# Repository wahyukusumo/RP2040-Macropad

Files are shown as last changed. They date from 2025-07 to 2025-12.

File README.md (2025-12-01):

# RP2040 Macropad

This is a macropad firmware for Raspberry Pi Pico RP2040 written in Circuitpython. This firmware support up to 8 rotary encoders, 20 buttons, and a TFT display. Or you can just adjust it like however you like.

### Table of Contents
- [RP2040 Macropad](#rp2040-macropad)
    - [Table of Contents](#table-of-contents)
    - [Features](#features)
  - [🛠 Build](#-build)
    - [Hardwares Needed](#hardwares-needed)
    - [Schematic](#schematic)
    - [Software](#software)
    - [Installation](#installation)
    - [Configuration](#configuration)
    - [My Build Log](#my-build-log)

### Features

- 6 Rotary encoders.
- 240\*240 TFT Display to display information and image or gif. <sup><sub>*RP2040 will struggle to play gif btw</sub></sup>
-  [deej](https://github.com/omriharel/deej) rotary encoder support.

## 🛠 Build

You can adjust this build to fil what you need

### Hardwares Needed

- Raspberry Pi Pico
- 2 Expansion Board PCF8574
- 6 EC11 Rotary encoders
- 20 button switches
- ST7789 TFT Display
- Prefboard
- Wires

### Schematic

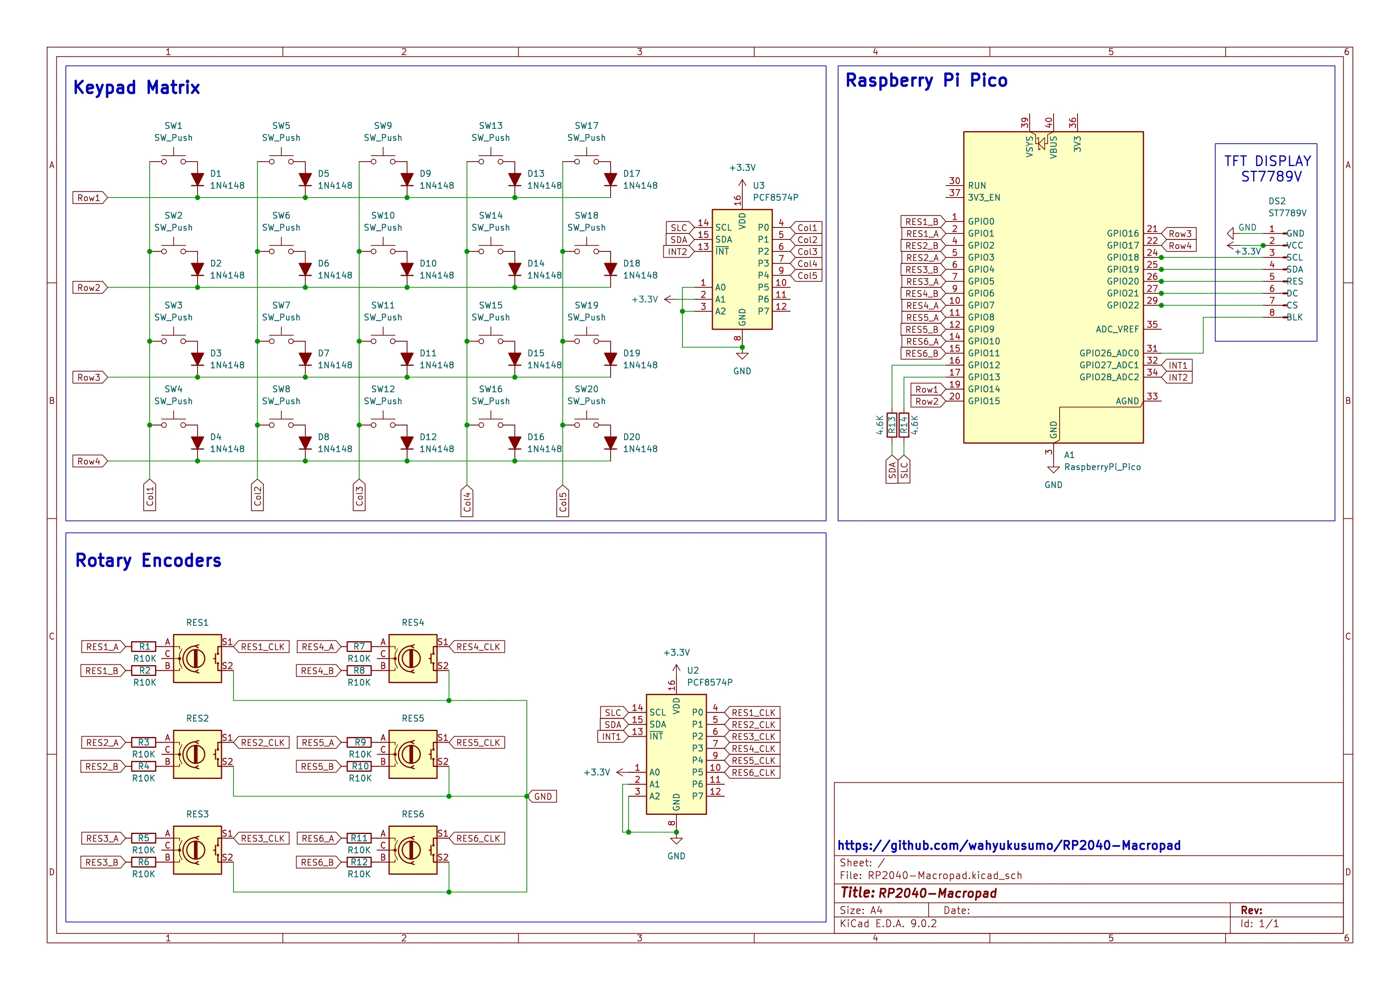
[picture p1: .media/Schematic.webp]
Schematic


### Software

- [Circuitpython v9](https://circuitpython.org/board/raspberry_pi_pico/)
- [Convert image to BMP](https://online-converting.com/image/convert2bmp/)
- [MPY Cross](https://adafruit-circuit-python.s3.amazonaws.com/index.html?prefix=bin/mpy-cross/windows/)

### Installation

- Install Circuitpython v9 to your Pi Pico
- Download or clone this repository
- Move all files inside _lib/lib-circuitpython-v9_ to your Pi Pico _lib_ folder
- Copy these file from this repository to your Pi Pico:
  - _config.py_
  - _code.py_
- If you want use custom font, you 
- This is what your Pi Pico directory should look like:
```
│   boot_out.txt
│   code.py
│   config.py
├───lib
│   │   adafruit_pcf8574.mpy
│   │   adafruit_pioasm.mpy
│   │   adafruit_st7789.mpy
│   │   deej.py
│   │   digitalio.mpy
│   │   rotaryio.mpy
│   │   rp2pio_dualincrementalencoder.mpy
│   │   macropad.mpy
│   │   display.mpy
│
├───media
├───fonts
```

### Configuration
- _config.py_ is to assign your microcontroller pins.
- _code.py_ is to assign your buttons and encoders actions.

### My Build Log
 _Update later..._

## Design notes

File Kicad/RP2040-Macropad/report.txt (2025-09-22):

Plotted to 'C:\Users\yvma\Documents\KiCad\RP2040-Macropad\RP2040-Macropad.pdf'.

Info: Done.
Info: Done.

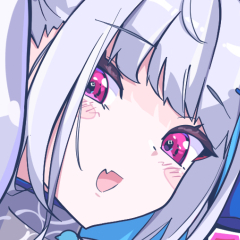
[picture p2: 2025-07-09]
image-to-bmp/myimages.jpg

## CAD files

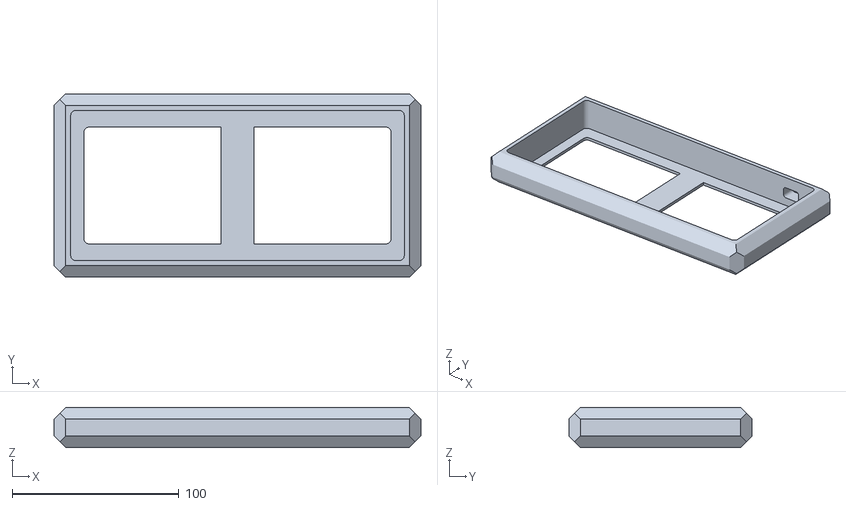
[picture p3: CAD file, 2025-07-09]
Case/macropad-trim.stl
220.0 x 110.0 x 24.0

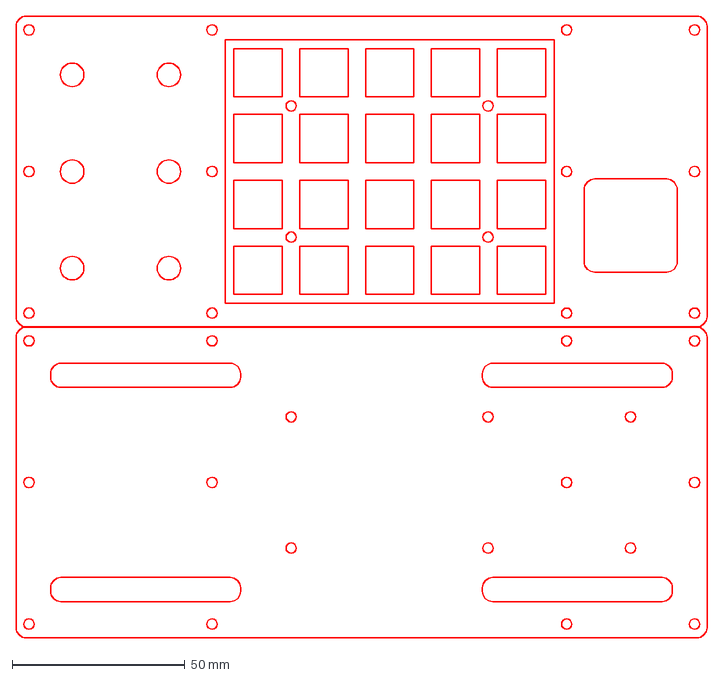
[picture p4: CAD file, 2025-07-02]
Case/macropad-ws2812.dxf
200.0 x 180.0 mm

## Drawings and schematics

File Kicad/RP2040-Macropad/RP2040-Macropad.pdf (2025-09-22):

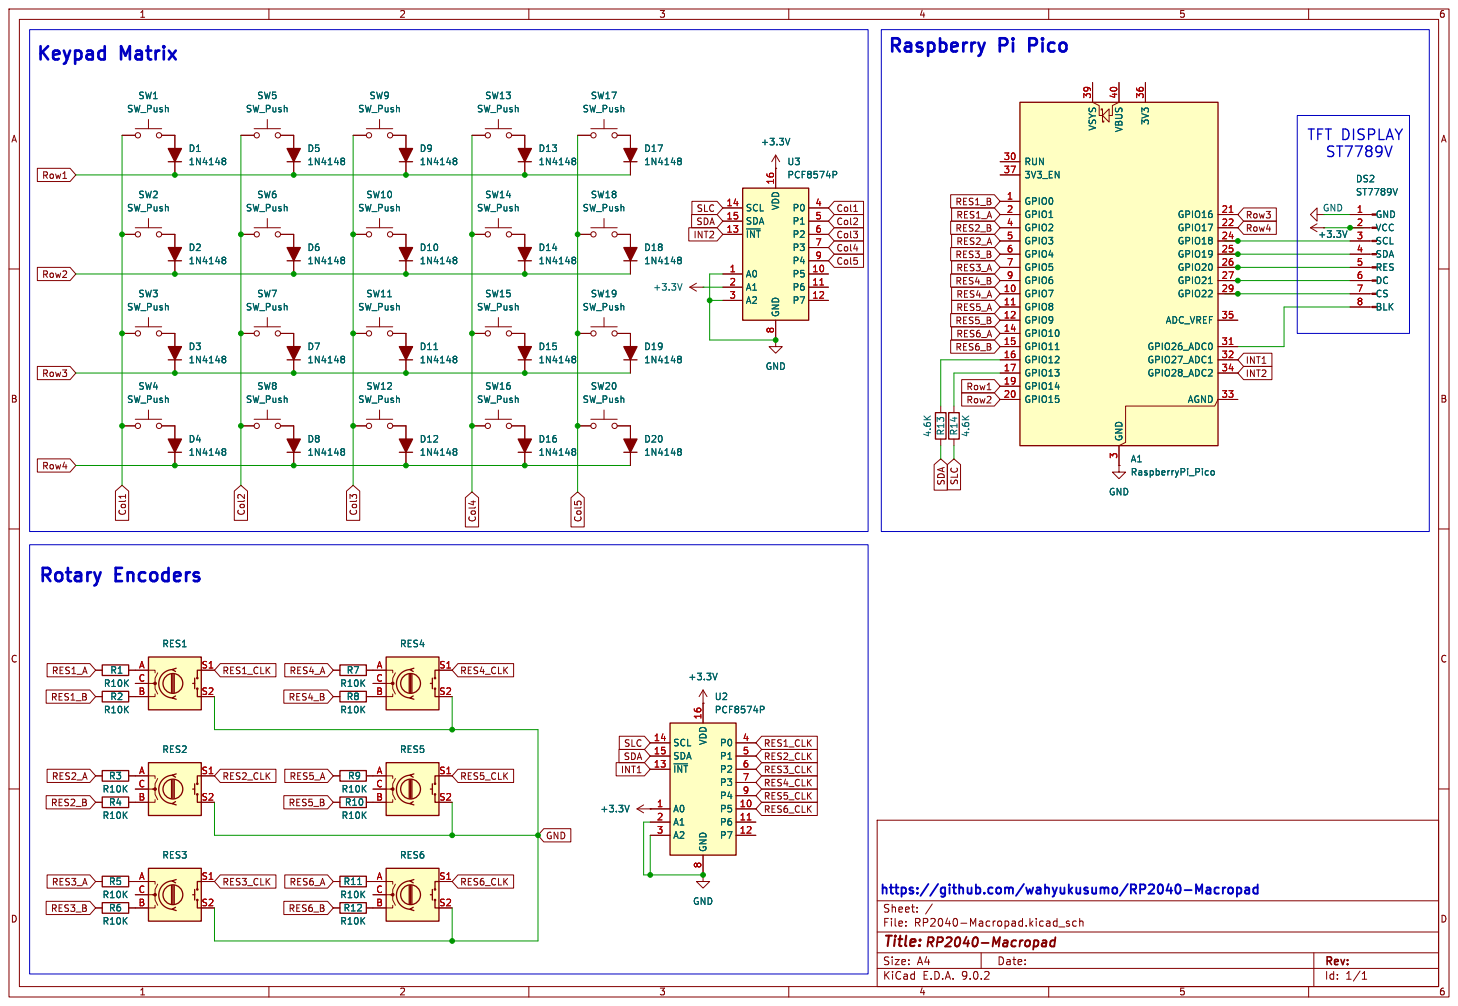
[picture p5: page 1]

INT2 RES6_A RES2_B RES1_A RES1_B RES6_B RES2_A RES3_B RES5_A RES4_A RES5_B RES4_B RES3_A https://github.com/wahyukusumo/RP2040-Macropad

Id: 1/1 Title: File: RP2040-Macropad.kicad_sch Sheet: / R3 R10K

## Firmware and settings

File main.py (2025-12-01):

import time
import board
import busio
import display
import config
from deej import Deej
from macropad import (
    HIDType as hid,
    ButtonInputType as BiT,
    Button,
    SplitRotaryEncoder,
    ButtonMatrix,
)
from adafruit_pcf8574 import PCF8574
from adafruit_hid.keycode import Keycode as key
from rp2pio_dualincrementalencoder import DualIncrementalEncoder
from adafruit_hid.consumer_control_code import ConsumerControlCode as cc_code


DEEJ = Deej(config.DEEJ_PROGRAMS)

SCREEN = display.DisplayScreen(
    pin_clock=config.DISPLAY_PINS["CLOCK"],
    pin_mosi=config.DISPLAY_PINS["MOSI"],
    pin_cs=config.DISPLAY_PINS["CS"],
    pin_dc=config.DISPLAY_PINS["DC"],
    pin_reset=config.DISPLAY_PINS["RESET"],
    pin_bl=config.DISPLAY_PINS["BL"],
    rotation=config.DISPLAY_PINS["ROTATION"],
)

ENCODERS, KEYPADS = config.input_map(SCREEN, DEEJ, BiT, key, hid, cc_code)


def init_expander(scl, sda):
    i2c = busio.I2C(scl, sda)
    # Wait for I2C to be ready
    while not i2c.try_lock():
        pass
    i2c.unlock()
    return i2c


def init_encoders(encoders_num):
    """This loop is for looping through encoders pin and .
    So if there's 6 rotary encoders, encoders_num = 6
    (0, 6 * 2, 4) mean we start from 0, and since each encoder have 2 pins, multiplied by 2.
    DualIncrementalEncoder require 4 pins so we split it by 4
    and it will append to dual_encoders as 3 object of DualIncrementalEncoder
    """
    dual_encoders = []
    for i in range(0, encoders_num * 2, 4):
        pins = [getattr(board, f"GP{j}") for j in range(i, i + 4)]
        init_dual_encoder = DualIncrementalEncoder(*pins)
        dual_encoders.append(init_dual_encoder)

    """ After we get DualIncrementalEncoders we need to get value of each encoder and
    apply action of the encoders
    """
    encoders = []
    for i in range(encoders_num):
        group = i // 2  # integer division groups every two items
        local_index = i % 2  # 0 or 1
        split_encoder = SplitRotaryEncoder(
            name=f"Encoder {i}",
            encoder=dual_encoders[group],
            index=local_index,
            actions=ENCODERS[config.ROTARY_ENCODERS_PHYSICAL_ORDER[i] - 1]["actions"],
        )
        encoders.append(split_encoder)

    return encoders


def init_button_encoders(i2c):
    expander = PCF8574(i2c, address=config.BUTTON_IO_EXPANDER_ADDRESS)
    buttons = []

    for encoder in ENCODERS:
        button_pin = expander.get_pin(encoder["button"]["pin"])
        button = Button(pin_button=button_pin, actions=encoder["button"]["actions"])
        buttons.append(button)
    return buttons


def init_volumes_label():
    labels = []
    for i in range(DEEJ.num_programs):
        y = 50 + (i - 1) * 25
        text = f"{DEEJ.volumes[i]} - {DEEJ.programs[i]}"
        label = SCREEN.label(text, x=15, y=y)
        labels.append(label)
    return labels


def main():
    i2c = init_expander(
        scl=config.IO_EXPANDER_PINS["SCL"], sda=config.IO_EXPANDER_PINS["SDA"]
    )

    encoders = init_encoders(config.ROTARY_ENCODERS_NUM)
    encoder_buttons = init_button_encoders(i2c)

    keypad = ButtonMatrix(
        actions=KEYPADS,
        expander=PCF8574(i2c, address=config.MATRIX_IO_EXPANDER_ADDRESS),
        rows=config.MATRIX_ROW_PINS,
        columns=config.MATRIX_COL_PINS,
    )

    if config.USE_DEEJ:
        labels = init_volumes_label()

    slideshow = display.Slideshow(SCREEN.images_group)
    # gif = display.PlayGif("media/mon.gif", SCREEN.gif_group, SCREEN.display)
    SCREEN.show_screen()

    while True:
        for encoder in encoders:
            turned = encoder.encoder_action()

            if turned and config.USE_DEEJ:
                labels[DEEJ.current].text = DEEJ.display

        for button in encoder_buttons:
            button.button_action()

        keypad.matrix_scanning()
        slideshow.update()
        # gif.update_gif()

        time.sleep(0.01)


if __name__ == "__main__":
    main()

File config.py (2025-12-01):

import board

IO_EXPANDER_PINS = {"SDA": board.GP12, "SCL": board.GP13}
MATRIX_IO_EXPANDER_ADDRESS = 0x25
BUTTON_IO_EXPANDER_ADDRESS = 0x20
DEEJ_PROGRAMS = ["Master", "Firefox", "Spotify", "Discord", "Apex"]

USE_DEEJ = False
DISPLAY_PINS = {
    "CLOCK": board.GP18,
    "MOSI": board.GP19,
    "CS": board.GP20,
    "DC": board.GP21,
    "RESET": board.GP22,
    "BL": board.GP23,
    "ROTATION": 180,
}

MATRIX_ROW_PINS = [board.GP14, board.GP15, board.GP17, board.GP24]
MATRIX_COL_PINS = [0, 1, 2, 3, 4]

ROTARY_ENCODERS_NUM = 6
ROTARY_ENCODERS_PHYSICAL_ORDER = [1, 6, 4, 2, 5, 3]
"""This is for physical order of rotary encoder, in practice your physical 
rotary encoder position must same as gpio pin, like:

|ENC1 (gpio 0, gpio 1)|ENC2 (gpio 2, gpio 3)|
|ENC3 (gpio 4, gpio 5)|ENC4 (gpio 6, gpio 7)|
|ENC5 (gpio 8, gpio 9)|ENC6 (gpio 10, gpio 11)|

but if your wiring not in order, you still can reorder it
without changing the wiring.
"""


def input_map(screen, deej, BiT, key, hid, cc_code):
    ENCODERS = [
        {  # Encoder 1
            "actions": (
                # lambda: SCREEN.change_brightness(-1),
                # lambda: SCREEN.change_brightness(+1),
                lambda: hid.KBD.send(key.CONTROL, key.Z),
                lambda: hid.KBD.send(key.CONTROL, key.SHIFT, key.Z),
            ),
            "button": {"pin": 1, "actions": (BiT.KEY, [key.ONE])},
        },
        {  # Encoder 2
            "actions": (
                # lambda: DEEJ.change_volume(-5),
                # lambda: DEEJ.change_volume(+5),
                lambda: SCREEN.change_brightness(-1),
                lambda: SCREEN.change_brightness(+1),
            ),
            "button": {"pin": 0, "actions": (BiT.KEY, [key.TWO])},
        },
        {  # Encoder 3
            "actions": (
                lambda: hid.MOUSE.move(wheel=-1),
                lambda: hid.MOUSE.move(wheel=1),
            ),
            "button": {"pin": 3, "actions": (BiT.KEY, [key.TWO])},
        },
        {  # Encoder 4
            "actions": (
                lambda: hid.KBD.send(key.CONTROL, key.LEFT_BRACKET),
                lambda: hid.KBD.send(key.CONTROL, key.RIGHT_BRACKET),
            ),
            "button": {"pin": 2, "actions": (BiT.KEY, [key.FIVE])},
        },
        {  # Encoder 5
            "actions": (
                lambda: hid.KBD.send(key.CONTROL, key.Z),
                lambda: hid.KBD.send(key.CONTROL, key.SHIFT, key.Z),
            ),
            "button": {"pin": 4, "actions": (BiT.KEY, [key.FIVE])},
        },
        {  # Encoder 6
            "actions": (
                lambda: hid.KBD.send(key.CONTROL, key.ALT, key.ONE),
                lambda: hid.KBD.send(key.CONTROL, key.ALT, key.TWO),
                lambda: hid.KBD.send(key.CONTROL, key.ALT, key.THREE),
            ),
            "button": {"pin": 5, "actions": (BiT.KEY, [key.FORWARD_SLASH])},
        },
    ]

    KEYPADS = [
        [  # Row 1
            (BiT.CUSTOM, lambda: DEEJ.cycle_programs(-1)),
            (BiT.MEDIA, cc_code.SCAN_PREVIOUS_TRACK),
            (BiT.MEDIA, cc_code.PLAY_PAUSE),
            (BiT.MEDIA, cc_code.SCAN_NEXT_TRACK),
            (BiT.CUSTOM, lambda: DEEJ.cycle_programs(+1)),
        ],
        [  # Row 2
            (BiT.KEY, [key.INSERT]),
            (BiT.KEY, [key.SHIFT, key.DELETE]),
            (BiT.KEY, [key.CONTROL, key.ALT, key.SHIFT, key.V]),
            (BiT.KEY, [key.CONTROL, key.T]),
            (BiT.KEY, [key.CONTROL, key.SHIFT, key.A]),
        ],
        [  # Row 3
            (BiT.KEY, [key.SPACE]),
            (BiT.KEY, [key.B]),
            (BiT.KEY, [key.M]),
            (BiT.KEY, [key.N]),
            (BiT.KEY, [key.O]),
        ],
        [  # Row 4
            (BiT.KEY, [key.SHIFT]),
            (BiT.KEY, [key.CONTROL]),
            (BiT.KEY, [key.R]),
            (BiT.KEY, [key.S]),
            (BiT.KEY, [key.T]),
        ],
    ]

    return ENCODERS, KEYPADS

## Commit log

2025-03-31 Initial commit.
    My first macropad using 3 rotary encoders and 10 buttons.
2025-04-01 Create encoder function to keep code DRY
2025-04-01 Move code about buttons to different function since it will be rewrite later
2025-04-01 Create Button class and extend it to RotaryEncoder class
2025-04-01 Add button and rotary encoder action argument by changing classes argument from pin only into pin/action pair
2025-04-01 Complete code for 4 rotary encoders
2025-04-01 Split pin action pair argument, make actions separate as a tuple and when actions more than 2, rotary encoder will wrap around action
2025-07-02 Add dual rotary encoder library
    This library by todbot for using more than 4 rotary encoders. (https://github.com/todbot/pico8enc/blob/main/firmware/rp2pio_dualincrementalencoder.py)
2025-07-02 Add acrylic case svg
    [macropad-ws2812.dxf]
2025-07-04 Create macropad library for Button and RotaryEncoder class so its separate from code.py for cleaner and more managable code
2025-07-04 Change button_state value from 0/1 to True/False
2025-07-04 Add new function for button that used interupt pin
2025-07-04 Renamed handle_button to button_action and now can handle button matrix, single pin, or that used extender
2025-07-04 Change PCF8674 library to allow pull=None in switch_to_input function
2025-07-04 Add new DualRotaryEncoder since rotaryio only support 4 encoders, this dualencoders support up to 8 encoders
2025-07-04 Add button matrix scanning, use pcf extender as input and gpio as output
2025-07-09 Add stl file of body trim
    [macropad-trim.stl]
2025-07-09 Remove button inheretance from original rotary encoder function
2025-07-11 Add encoders function in macropad
2025-07-11 Implement button encoder action on macropad
2025-07-11 Adjust encoders action so its in order from 1-6 in code since it's pin hardware is unordered
2025-09-22 Add Kicad project files
    [RP2040-Macropad.kicad_pcb, RP2040-Macropad.kicad_sch]
